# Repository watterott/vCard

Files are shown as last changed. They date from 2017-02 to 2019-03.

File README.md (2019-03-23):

# vCard
vCard is an business card with 12 x 8 LED-Matrix (total 96 LEDs) and AVR microcontroller.

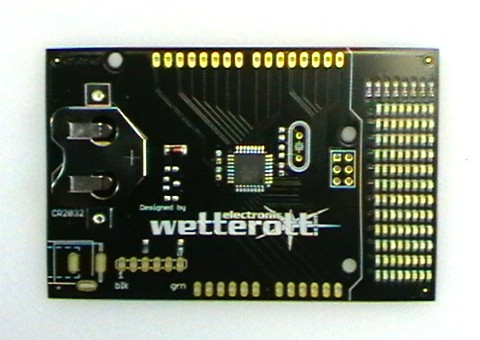
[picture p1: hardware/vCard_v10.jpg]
vCard


* Microchip ATmega328P with Arduino compatible Bootloader (optiboot)
* 12 x 8 LED-Matrix
* Power Supply: CR2032 (3V) / LIR2032 (3.6V) cell battery
* Open-Source and released under the [Creative Commons Attribution Share-Alike License](https://creativecommons.org/licenses/by-sa/4.0/).

## Hardware
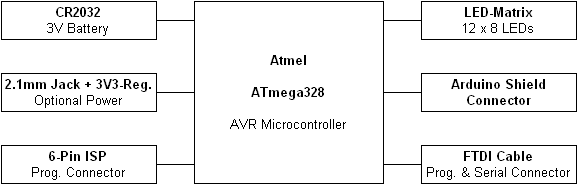
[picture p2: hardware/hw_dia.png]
vCard hardware dia
* 
* [Schematics + Layout](https://github.com/watterott/vCard/tree/master/hardware)
* **Note: When using an external power supply (eg via the FTDI port) always remove the battery.**

## Software
* [Arduino Examples](https://github.com/watterott/vCard/tree/master/software)
* [vCard Online Frame Editor](http://vcard.pipefishbook.com/)

## Videos
vCard (https://www.youtube.com/watch?v=DOjuRTCZP2k)

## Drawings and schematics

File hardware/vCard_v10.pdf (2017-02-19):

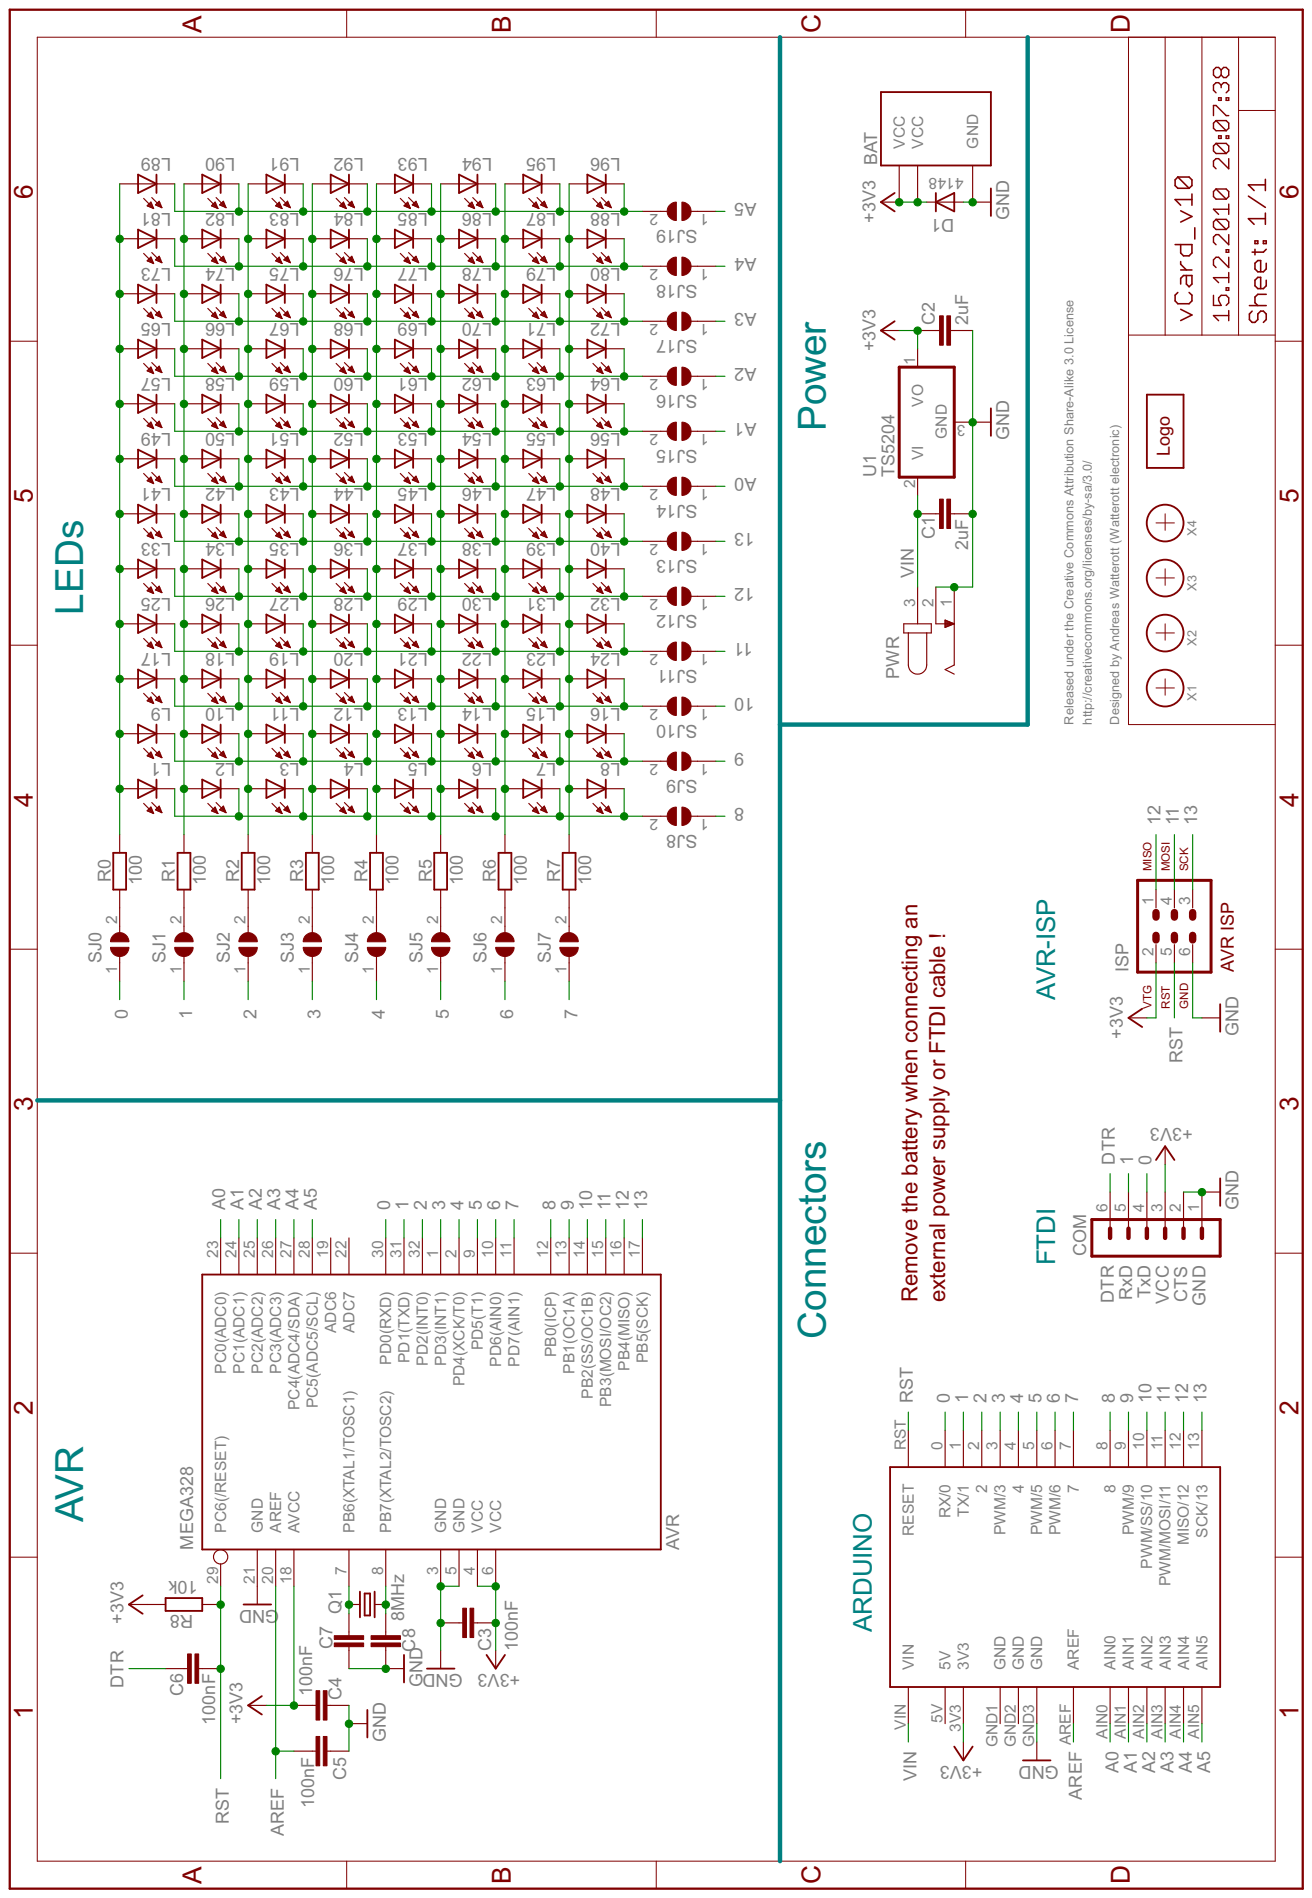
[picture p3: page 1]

Released under the Creative Commons Attribution Share-Alike 3.0 License

http://creativecommons.org/licenses/by-sa/3.0/ Designed by Andreas Watterott (Watterott electronic) GND

MOSI SCK MISO VTG

ove the battery when connecting an

PB4(MISO) 16 PB3(MOSI/OC2) 15 PB2(SS/OC1B) 14 PB1(OC1A) 13 PB0(ICP) 12 PD7(AIN1) 11 PD6(AIN0) 10 PD5(T1) 9 PD4(XCK/T0) 2 PD3(INT1) 1 PD2(INT0) 32 PD1(TXD) 31 PD0(RXD) 30 ADC7

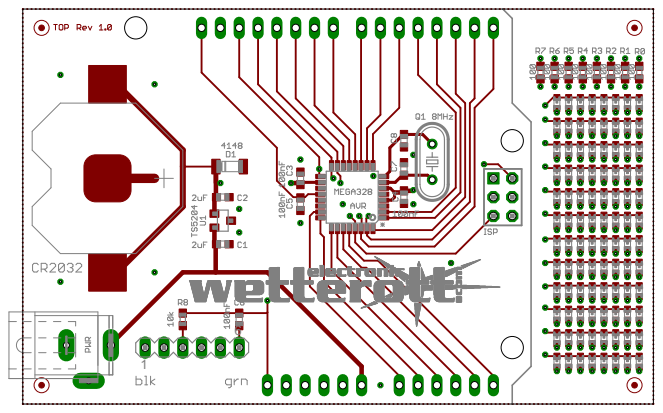
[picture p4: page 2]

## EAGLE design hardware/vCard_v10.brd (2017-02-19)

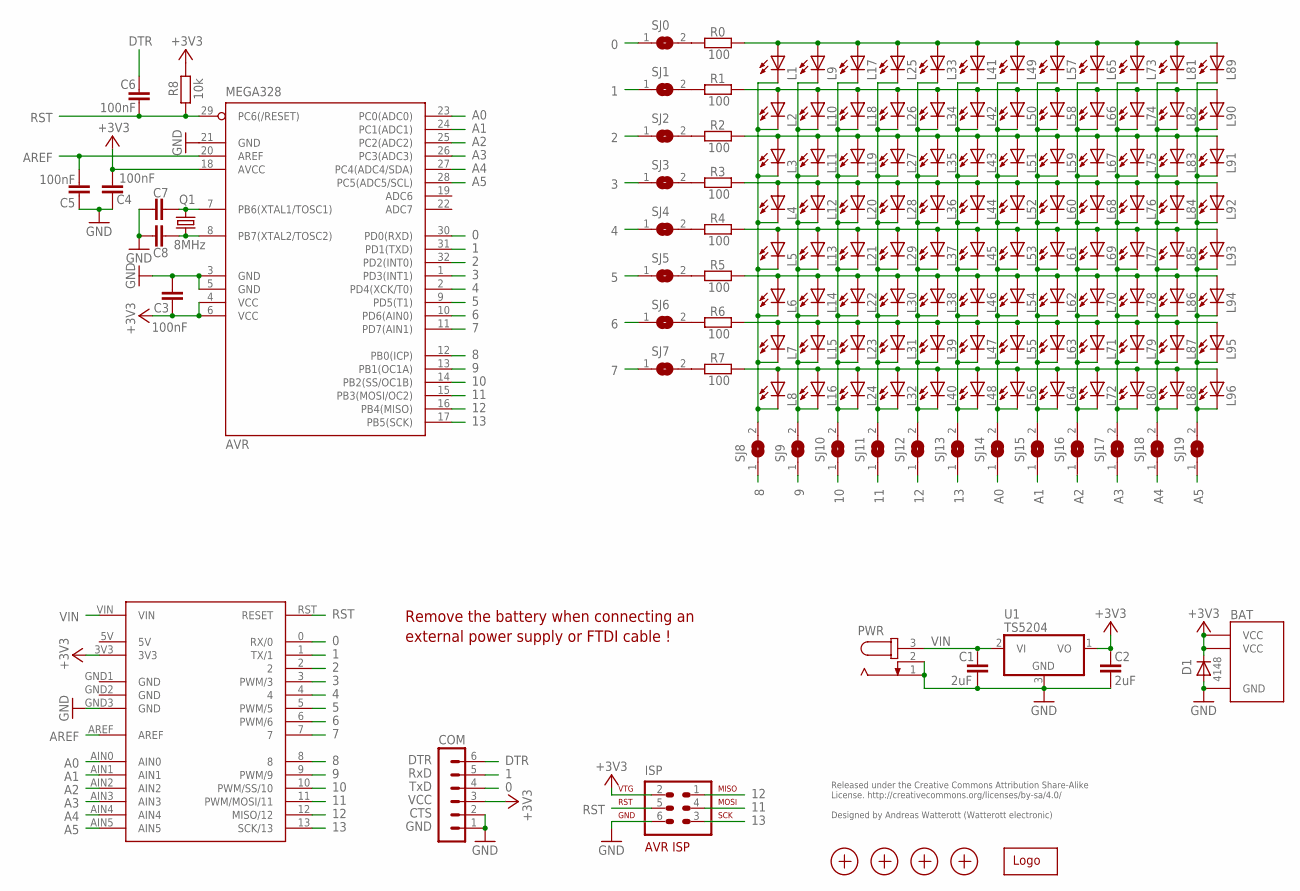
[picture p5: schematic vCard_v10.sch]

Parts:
ARDUINO: UNO; DUEMILANOVE2
AVR: MEGA328; TQFP32-08
BAT: KC3002S
C1, C2: 2uF; C0603
C3, C4, C5, C6: 100nF; C0603
C7, C8: C-EUC0603; C0603
COM: MA06-1
D1: 4148; MLL34
ISP: AVR-ISP-6
L1, L2, L3, L4, L5, L6, L7, L8, L9, L10, L11, L12, L13, L14, L15, L16, L17, L18, L19, L20, L21, L22, L23, L24, L25, L26, L27, L28, L29, L30, L31, L32, L33, L34, L35, L36, L37, L38, L39, L40, L41, L42, L43, L44, L45, L46, L47, L48, L49, L50, L51, L52, L53, L54, L55, L56, L57, L58, L59, L60, L61, L62, L63, L64, L65, L66, L67, L68, L69, L70, L71, L72, L73, L74, L75, L76, L77, L78, L79, L80, L81, L82, L83, L84, L85, L86, L87, L88, L89, L90, L91, L92, L93, L94, L95, L96: LEDCHIPLED_0603; CHIPLED_0603
LOGO1: WE-LOGO
PWR: JACK-PLUG0; SPC4077
Q1: 8MHz; HC49/S
R0, R1, R2, R3, R4, R5, R6, R7: 100; R0603
R8: 10k; R0603
SJ0, SJ1, SJ2, SJ3, SJ4, SJ5, SJ6, SJ7, SJ8, SJ9, SJ10, SJ11, SJ12, SJ13, SJ14, SJ15, SJ16, SJ17, SJ18, SJ19: SJ
U1: TS5204; SOT23
X1, X2, X3, X4: PASSER

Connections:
0: ARDUINO.0 (RX/0), AVR.30 (PD0(RXD)), COM.4, SJ0.1
1: ARDUINO.1 (TX/1), AVR.31 (PD1(TXD)), COM.5, SJ1.1
2: ARDUINO.2, AVR.32 (PD2(INT0)), SJ2.1
3: ARDUINO.3 (PWM/3), AVR.1 (PD3(INT1)), SJ3.1
4: ARDUINO.4, AVR.2 (PD4(XCK/T0)), SJ4.1
5: ARDUINO.5 (PWM/5), AVR.9 (PD5(T1)), SJ5.1
5V: ARDUINO.5V
6: ARDUINO.6 (PWM/6), AVR.10 (PD6(AIN0)), SJ6.1
7: ARDUINO.7, AVR.11 (PD7(AIN1)), SJ7.1
8: ARDUINO.8, AVR.12 (PB0(ICP)), SJ8.1
8_: L1.C, L2.C, L3.C, L4.C, L5.C, L6.C, L7.C, L8.C, SJ8.2
9: ARDUINO.9 (PWM/9), AVR.13 (PB1(OC1A)), SJ9.1
9_: L9.C, L10.C, L11.C, L12.C, L13.C, L14.C, L15.C, L16.C, SJ9.2
10: ARDUINO.10 (PWM/SS/10), AVR.14 (PB2(SS/OC1B)), SJ10.1
10_: L17.C, L18.C, L19.C, L20.C, L21.C, L22.C, L23.C, L24.C, SJ10.2
11: ARDUINO.11 (PWM/MOSI/11), AVR.15 (PB3(MOSI/OC2)), ISP.4, SJ11.1
11_: L25.C, L26.C, L27.C, L28.C, L29.C, L30.C, L31.C, L32.C, SJ11.2
12: ARDUINO.12 (MISO/12), AVR.16 (PB4(MISO)), ISP.1, SJ12.1
12_: L33.C, L34.C, L35.C, L36.C, L37.C, L38.C, L39.C, L40.C, SJ12.2
13: ARDUINO.13 (SCK/13), AVR.17 (PB5(SCK)), ISP.3, SJ13.1
13_: L41.C, L42.C, L43.C, L44.C, L45.C, L46.C, L47.C, L48.C, SJ13.2
+3V3: ARDUINO.3V3, AVR.4 (VCC), AVR.6 (VCC), AVR.18 (AVCC), BAT.VCC1 (VCC), BAT.VCC2 (VCC), C2.1, C3.2, C4.2, COM.3, D1.1 (K), ISP.2, R8.2, U1.1 (VO)
A0: ARDUINO.AIN0, AVR.23 (PC0(ADC0)), SJ14.1
A0_: L49.C, L50.C, L51.C, L52.C, L53.C, L54.C, L55.C, L56.C, SJ14.2
A1: ARDUINO.AIN1, AVR.24 (PC1(ADC1)), SJ15.1
A1_: L57.C, L58.C, L59.C, L60.C, L61.C, L62.C, L63.C, L64.C, SJ15.2
A2: ARDUINO.AIN2, AVR.25 (PC2(ADC2)), SJ16.1
A2_: L65.C, L66.C, L67.C, L68.C, L69.C, L70.C, L71.C, L72.C, SJ16.2
A3: ARDUINO.AIN3, AVR.26 (PC3(ADC3)), SJ17.1
A3_: L73.C, L74.C, L75.C, L76.C, L77.C, L78.C, L79.C, L80.C, SJ17.2
A4: ARDUINO.AIN4, AVR.27 (PC4(ADC4/SDA)), SJ18.1
A4_: L81.C, L82.C, L83.C, L84.C, L85.C, L86.C, L87.C, L88.C, SJ18.2
A5: ARDUINO.AIN5, AVR.28 (PC5(ADC5/SCL)), SJ19.1
A5_: L89.C, L90.C, L91.C, L92.C, L93.C, L94.C, L95.C, L96.C, SJ19.2
AREF: ARDUINO.AREF, AVR.20 (AREF), C5.2
DTR: C6.1, COM.6
GND: ARDUINO.GND1 (GND), ARDUINO.GND2 (GND), ARDUINO.GND3 (GND), AVR.3 (GND), AVR.5 (GND), AVR.21 (GND), BAT.GND, C1.2, C2.2, C3.1, C4.1, C5.1, C7.2, C8.2, COM.1, COM.2, D1.2 (A), ISP.6, PWR.1, PWR.2, U1.3 (GND)
unnamed: L1.A, L9.A, L17.A, L25.A, L33.A, L41.A, L49.A, L57.A, L65.A, L73.A, L81.A, L89.A, R0.2
unnamed: AVR.8 (PB7(XTAL2/TOSC2)), C8.1, Q1.1
unnamed: AVR.7 (PB6(XTAL1/TOSC1)), C7.1, Q1.2
unnamed: R0.1, SJ0.2
unnamed: R1.1, SJ1.2
unnamed: R2.1, SJ2.2
unnamed: R3.1, SJ3.2
unnamed: R4.1, SJ4.2
unnamed: R5.1, SJ5.2
unnamed: R6.1, SJ6.2
unnamed: R7.1, SJ7.2
unnamed: L2.A, L10.A, L18.A, L26.A, L34.A, L42.A, L50.A, L58.A, L66.A, L74.A, L82.A, L90.A, R1.2
unnamed: L3.A, L11.A, L19.A, L27.A, L35.A, L43.A, L51.A, L59.A, L67.A, L75.A, L83.A, L91.A, R2.2
unnamed: L4.A, L12.A, L20.A, L28.A, L36.A, L44.A, L52.A, L60.A, L68.A, L76.A, L84.A, L92.A, R3.2
unnamed: L5.A, L13.A, L21.A, L29.A, L37.A, L45.A, L53.A, L61.A, L69.A, L77.A, L85.A, L93.A, R4.2
unnamed: L6.A, L14.A, L22.A, L30.A, L38.A, L46.A, L54.A, L62.A, L70.A, L78.A, L86.A, L94.A, R5.2
unnamed: L7.A, L15.A, L23.A, L31.A, L39.A, L47.A, L55.A, L63.A, L71.A, L79.A, L87.A, L95.A, R6.2
unnamed: L8.A, L16.A, L24.A, L32.A, L40.A, L48.A, L56.A, L64.A, L72.A, L80.A, L88.A, L96.A, R7.2
RST: ARDUINO.RST (RESET), AVR.29 (PC6(/RESET)), C6.2, ISP.5, R8.1
VIN: ARDUINO.VIN, C1.1, PWR.3, U1.2 (VI)

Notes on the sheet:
Released under the Creative Commons Attribution Share-Alike License. http://creativecommons.org/licenses/by-sa/4.0/ Designed by Andreas Watterott (Watterott electronic)
GND
CTS
VCC
TxD
RxD
DTR
Remove the battery when connecting an
external power supply or FTDI cable !

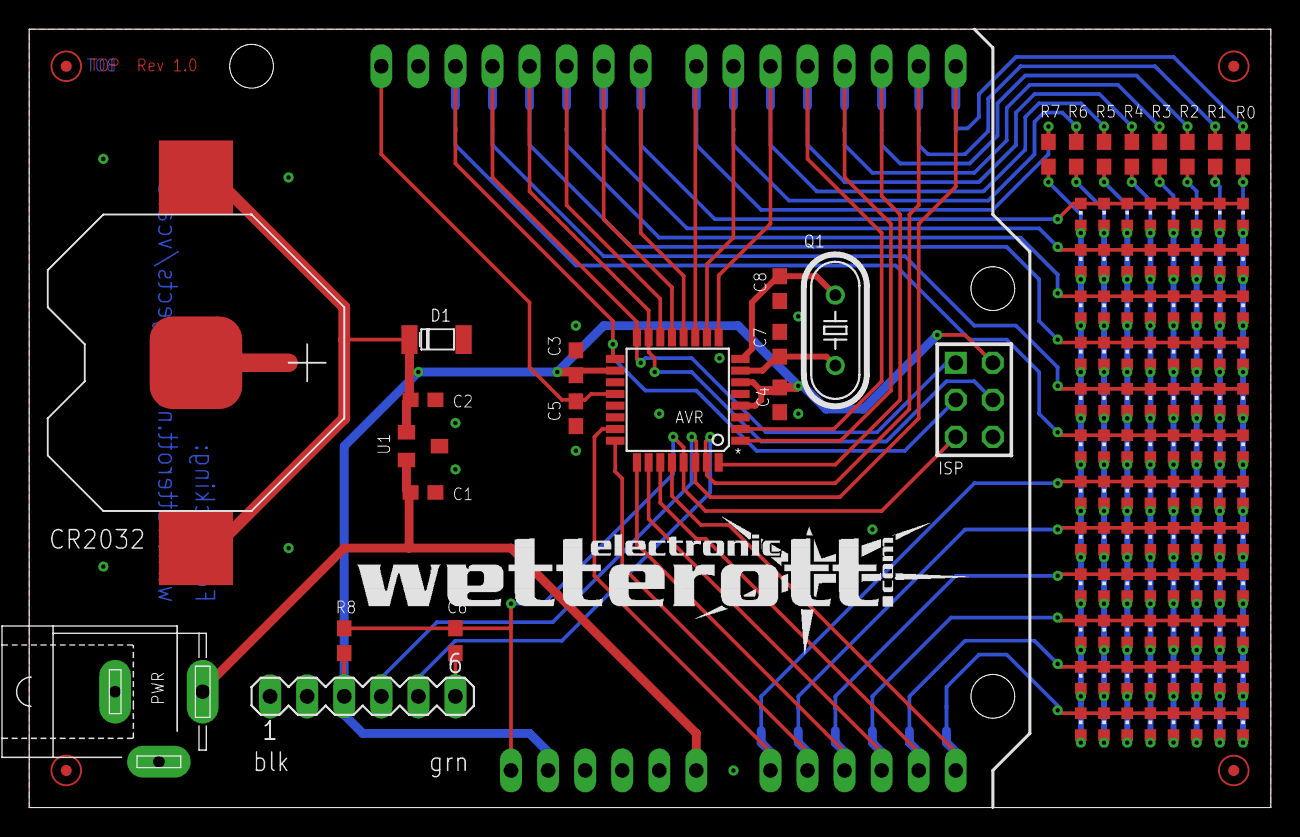
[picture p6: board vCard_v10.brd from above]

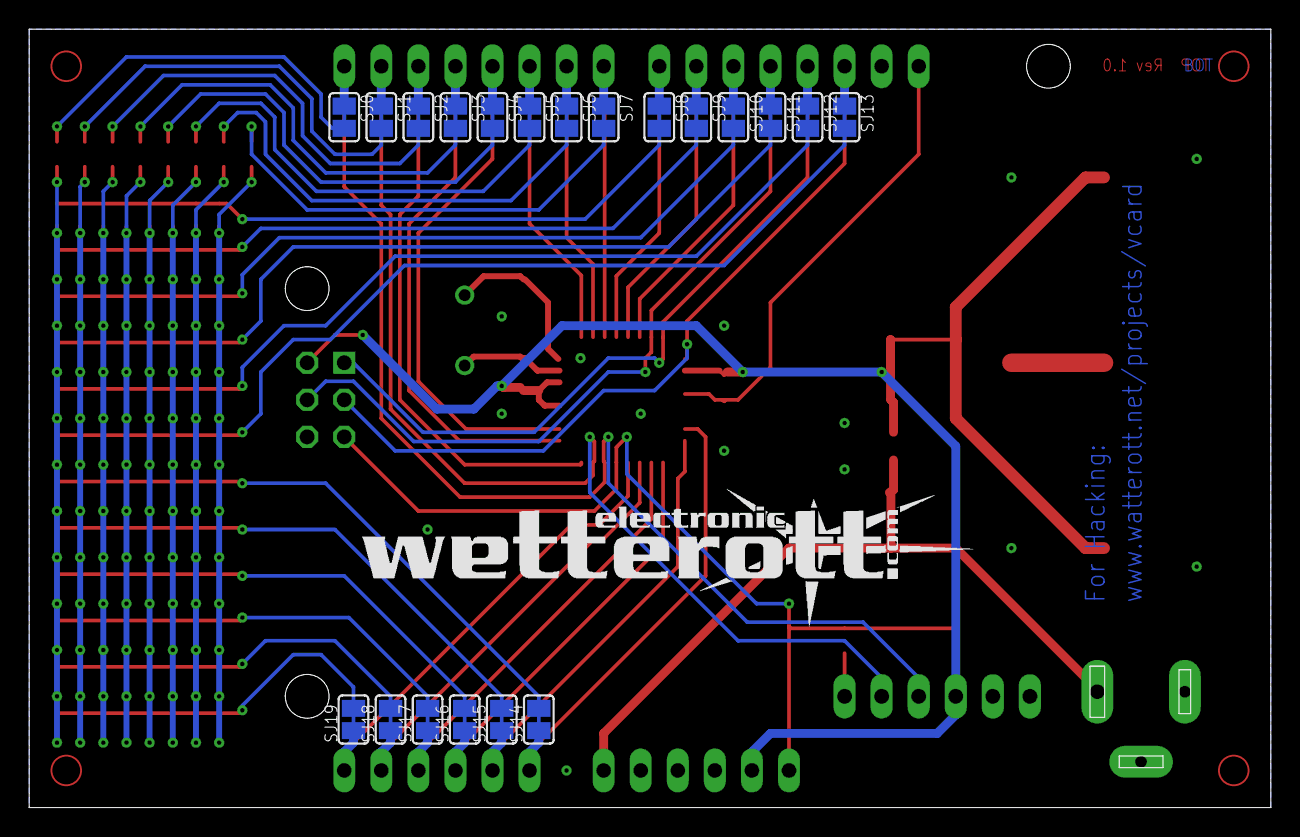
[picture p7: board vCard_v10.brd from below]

Board: 2 copper layers, 85.1 x 53.3 mm, 148 parts (21 on the bottom side), 56 nets.

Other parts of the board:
LOGO: WE-LOGO

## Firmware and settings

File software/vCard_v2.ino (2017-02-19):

/*
  vCard Demo App v2
  -----------------
  Select as Board: Arduino Pro (3.3V 8MHz) w/ ATmega328
*/


#include <inttypes.h>
#include <avr/pgmspace.h>
#include <util/delay.h>

/* ---------- image data ----------*/
#define start_w (48)
byte start_data[] PROGMEM = 
{
0x00,0xE3,0xE3,0x81,0x89,0x89,0x89,0x89,0xF7,0xF7,0x00,0x00,0x00,0x87,0xC7,0xE1,0xA1,0xB1,0x99,0x89,0xCF,0xC7,0x00,0x00,0x00,0x00,0x00,0x00,0x03,0x03,0xFF,0xFF,0x00,0x00,0x00,0x00,0x41,0x22,0x36,0x1C,0x3C,0xFF,0x3C,0x1C,0x1E,0x1A,0x11,0x10
};
#define pac_w (48)
byte pac_data[] PROGMEM = 
{
0x00,0x00,0x00,0x00,0x3C,0x7E,0xFF,0xFF,0xFD,0xEF,0x6E,0x2C,0x00,0x00,0x00,0x00,0x3C,0x7E,0xFF,0xFF,0xFD,0xE7,0x66,0x24,0x00,0x00,0x00,0x00,0x3C,0x7E,0xFF,0xFF,0xFD,0xE7,0x42,0x00,0x00,0x00,0x00,0x00,0x3C,0x7E,0xFF,0xFF,0xE5,0xC3,0x42,0x00
};
#define scroll_w (220)
byte scroll_data[] PROGMEM = 
{
0x00,0x00,0x00,0x00,0x00,0x00,0x00,0x00,0x00,0x00,0xFF,0x08,0x08,0x08,0x08,0xFF,0x00,0x78,0x94,0x94,0x94,0x58,0x00,0x00,0xFF,0x00,0xFF,0x00,0x78,0x84,0x84,0x84,0x78,0x00,0x00,0x00,0x80,0x00,0x00,0x00,0x03,0x3C,0xC0,0x30,0x0E,0x01,0x0E,0x30,0xC0,0x3C,0x03,0x78,0x84,0x84,0x84,0x78,0x00,0xFC,0x08,0x04,0x00,0x00,0xFF,0x00,0x78,0x84,0x84,0x48,0xFF,0x00,0x00,0x00,0x00,0x00,0xBF,0x00,0x00,0x00,0x00,0x00,0x00,0x00,0x00,0x41,0x22,0x36,0x1C,0x3C,0xFF,0x3C,0x1C,0x1E,0x1A,0x11,0x10,0x00,0x00,0x00,0x00,0x00,0x00,0x00,0x00,0x03,0x3C,0xC0,0x70,0x0E,0x01,0x0E,0x70,0xC0,0x3C,0x03,0x68,0x94,0x94,0x94,0xF8,0x00,0x04,0xFF,0x84,0x04,0xFF,0x84,0x00,0x78,0x94,0x94,0x94,0x58,0x00,0xFC,0x04,0x04,0x00,0x78,0x84,0x84,0x84,0x78,0x00,0x04,0xFF,0x84,0x04,0xFF,0x84,0x00,0x00,0x00,0x00,0x78,0x94,0x94,0x94,0x58,0x00,0xFF,0x00,0x78,0x94,0x94,0x94,0x58,0x00,0x78,0x84,0x84,0x84,0x48,0x00,0x04,0xFF,0x84,0x00,0xFC,0x04,0x04,0x00,0x78,0x84,0x84,0x84,0x78,0x00,0xFC,0x08,0x04,0x04,0xF8,0x00,0xFD,0x00,0x78,0x84,0x84,0x84,0x48,0x00,0x00,0x00,0x00,0x00,0x00,0x00,0x00,0x41,0x22,0x36,0x1C,0x3C,0xFF,0x3C,0x1C,0x1E,0x1A,0x11,0x10
};

/* ---------- led control data ----------*/
const byte led_port[12][2] = //0=PORTB, 1=PORTC
{
  {~(1<<0),    0xff},
  {~(1<<1),    0xff},
  {~(1<<2),    0xff},
  {~(1<<3),    0xff},
  {~(1<<4),    0xff},
  {~(1<<5),    0xff},
  {   0xff, ~(1<<0)},
  {   0xff, ~(1<<1)},
  {   0xff, ~(1<<2)},
  {   0xff, ~(1<<3)},
  {   0xff, ~(1<<4)},
  {   0xff, ~(1<<5)},
};
#define leds_off(x) { PORTB = 0xff;           PORTC = 0xff;           PORTD = 0x00; }
#define led_row(x)  { PORTB = led_port[x][0]; PORTC = led_port[x][1]; }

/* ---------- current frame ----------*/
byte frame[12];


#if   (F_CPU == 16000000)
# define TCNT_SUB 250 //1000Hz
# define COUNT      8 // 125Hz (every 8ms)
# define DELAY    500 //  80us (500us*12 = 6ms)
#elif (F_CPU ==  8000000)
# define TCNT_SUB 250 //500Hz
# define COUNT      4 //125Hz (every 8ms)
# define DELAY    500 //500us (500us*12 = 6ms)
#else
# warning clock not supported
#endif
ISR(TIMER2_OVF_vect) //Timer 2 Interrupt
{
  static uint8_t count=1;
  uint8_t x;

  TCNT2 -= TCNT_SUB;

  if(--count == 0)
  {
    count = COUNT;

    //draw frame
    for(x=0; x<12; x++)
    {
      PORTD = frame[x];
      led_row(x);
      _delay_us(DELAY);
    }
    leds_off();
  }
}


void set_pixel(uint8_t nr) //set pixel in frame
{
  frame[(nr>>3)] |= (1<<(nr&7));
}


void clr_pixel(uint8_t nr) //clear pixel in frame
{
  frame[(nr>>3)] &= ~(1<<(nr&7));
}


void set_row(uint8_t r, uint8_t d) //set row in frame
{
  if(r < 12)
  {
    frame[r] = d;
  }
}


void clr_row(uint8_t r) //clear row in frame
{
  if(r < 12)
  {
    frame[r] = 0x00;
  }
}


void set_frame(PGM_P s) //set complete frame (s = pointer to flash start addr)
{
  frame[ 0] = pgm_read_byte(s++);
  frame[ 1] = pgm_read_byte(s++);
  frame[ 2] = pgm_read_byte(s++);
  frame[ 3] = pgm_read_byte(s++);
  frame[ 4] = pgm_read_byte(s++);
  frame[ 5] = pgm_read_byte(s++);
  frame[ 6] = pgm_read_byte(s++);
  frame[ 7] = pgm_read_byte(s++);
  frame[ 8] = pgm_read_byte(s++);
  frame[ 9] = pgm_read_byte(s++);
  frame[10] = pgm_read_byte(s++);
  frame[11] = pgm_read_byte(s);
}


void set_frame_inv(PGM_P s) //set complete frame inverted (s = pointer to flash start addr)
{
  frame[ 0] = ~pgm_read_byte(s++);
  frame[ 1] = ~pgm_read_byte(s++);
  frame[ 2] = ~pgm_read_byte(s++);
  frame[ 3] = ~pgm_read_byte(s++);
  frame[ 4] = ~pgm_read_byte(s++);
  frame[ 5] = ~pgm_read_byte(s++);
  frame[ 6] = ~pgm_read_byte(s++);
  frame[ 7] = ~pgm_read_byte(s++);
  frame[ 8] = ~pgm_read_byte(s++);
  frame[ 9] = ~pgm_read_byte(s++);
  frame[10] = ~pgm_read_byte(s++);
  frame[11] = ~pgm_read_byte(s);
}


void clr_frame(void) //clear complete frame
{
  frame[0] = frame[1] = frame[2]  = frame[3]  =
  frame[4] = frame[5] = frame[6]  = frame[7]  =
  frame[8] = frame[9] = frame[10] = frame[11] = 0x00;
}


uint8_t running_light(void)
{
  static uint8_t dir=0, pos=0;

  if(dir & 0x01)
  {
    pos--;
  }
  else
  {
    pos++;
  }

  clr_frame();
  set_row(pos, 0xff);

  if((pos == 0) || (pos >= 11))
  {
    dir++;
    if(dir >= 4)
    {
      dir = 0;
      pos = 0;
      delay(90);
      clr_frame();
      return 1;
    }
  }

  delay(90);

  return 0;
}


uint8_t start_countdown(void)
{
  static uint8_t pos=0;

  set_frame((PGM_P)&start_data[pos]);

  if((pos+12) >= start_w)
  {
    pos = 0;
    delay(1000);
    return 1;
  }
  else
  {
    pos += 12;
  }

  delay(1000);

  return 0;
}


uint8_t pacman(void)
{
  static uint16_t pos=0, offset=0;
  uint16_t i, j;

  i = pos;
  j = 12;
  do
  {
    if(j)
    {
      set_row(i, pgm_read_byte((PGM_P)&pac_data[offset+j-1]));
      j--;
    }
    else
    {
      clr_row(i);
    }
    i--;
  }while(i!=(-1));
  delay(50-pos);
  
  offset += 12;
  if(offset >= pac_w)
  {
    offset = 0;
    if(pos >= 23)
    {
      pos = 0;
      delay(500);
      clr_frame();
      return 1;
    }
    else
    {
      pos += 1;
    }
  }

  return 0;
}


uint8_t scroll_text(void)
{
  static uint16_t pos=0;

  set_frame((PGM_P)&scroll_data[pos]);

  if((pos+12) >= scroll_w)
  {
    pos = 0;
    delay(3000);
    return 1;
  }
  else
  {
    pos += 1;
    delay(90);
  }

  return 0;
}


uint8_t gol_alive(uint8_t x, uint8_t y)
{
  if((x < 12) && (y < 8))
  {
    return frame[x] & (1<<y);
  }

  return 0;
}


uint8_t gol_neighbors(uint8_t x, uint8_t y)
{
  uint8_t count=0;

  //3 above
  if(gol_alive(x-1,y-1)){ count++; }
  if(gol_alive(x,  y-1)){ count++; }
  if(gol_alive(x+1,y-1)){ count++; }

  //2 on each side
  if(gol_alive(x-1,  y)){ count++; }
  if(gol_alive(x+1,  y)){ count++; }

  //3 below
  if(gol_alive(x-1,y+1)){ count++; }
  if(gol_alive(  x,y+1)){ count++; }
  if(gol_alive(x+1,y+1)){ count++; }

  return count;
}


uint8_t gol(void)
{
  static uint8_t generation=0;
  uint8_t x, y, count;
  byte buf[12];

  //update cells
  for(x=0; x < 12; x++)
  {
    buf[x] = frame[x];
    for(y=0; y < 8; y++)
    {
      count = gol_neighbors(x, y);
      if((count == 3) && !gol_alive(x, y))
      {
        buf[x] |= (1<<y); //new cell
      }
      if(((count < 2) || (count > 3)) && gol_alive(x, y))
      {
        buf[x] &= ~(1<<y); //cell dies
      }
    }
  }

  //copy buf to frame
  for(count=0; count < 12; count++)
  {
    frame[count] = buf[count];
  }

  delay(150);

  if(++generation > 60)
  {
    generation = 0;
    return 1;
  }

  return 0;
}


void setup()
{
  byte c;

  //check if manual reset, then pins -> input with pull-up
  c = MCUSR;
  if(c & (1<<EXTRF))
  {
    MCUSR = 0;
    PORTB = 0xFF;
    DDRB  = 0x00;
    PORTC = 0xFF;
    DDRC  = 0x00;
    PORTD = 0xFF;
    DDRD  = 0x00;
    delay(300);
  }

  //pins -> output
  DDRB  = 0xFF;
  DDRC  = 0xFF;
  DDRD  = 0xFF;

  leds_off();
  clr_frame();

  //init Timer2
  TCCR2B  = (1<<CS22); //clk=F_CPU/64
  TCNT2   = 0x00;
  TIMSK2 |= (1<<TOIE2); //enable overflow interupt

  //interrupts on
  sei();
}


void loop()
{
  static uint8_t state=0;

  switch(state)
  {
    case 0: //--- running light ---
      state += running_light();
      break;

    case 1: //--- start count down ---
      state += start_countdown();
      break;

    case 2: //--- pacman ---
      state += pacman();
      break;

    case 3: //--- scroll text ---
      state += scroll_text();
      break;

    case 4: //--- game of live ---
      state++;
      //make better content for game of live
      for(uint8_t i=0; i<12; i++)
      {
        frame[i] &= 0xE7;
      }
    case 5:
      if(gol())
      {
        state = 2;
      }
      break;
  }
}
